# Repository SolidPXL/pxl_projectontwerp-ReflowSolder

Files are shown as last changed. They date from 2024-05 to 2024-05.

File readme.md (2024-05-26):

Final exam project for the PXL course 'Project Ontwerp' (Translated 'Project design')

The goal was to design a product from start to finish and make a first prototype version and to present our project in front of our professors. We got scored on our PCB design, Case design, project pitch, documentation and our development during the project.

The project is inspired by the AfterEarth [Solder Reflow plate](https://github.com/AfterEarthLTD/Solder-Reflow-Plate/tree/main)

V1 is what was submitted for points. Plans are to fix the issues that have been found and release a V2

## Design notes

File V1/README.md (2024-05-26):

# Reflow Solder Plate Version 1

# WARNING:
### It is not recommended to make this project as there are tons of issues, see the 'Known issues' below

## Features
- 10x10cm hot plate
- EST 100W PCB hot plate
- Soldering with reflow curves
- LCD display with rotary encoder controls
- 3D printed casing
- Case temperature management with fan and temp sensor
- Fused power socket
- Multiple boards, compact assembly

## Guide
### Electronics
Download the provider gerber files and upload to your favorite PCB manufacturer. It is recommended to purchase a stencil too.
Settings for both PCBs:

| Setting | Value |
| --- | --- |
| Base Material | FR-4 |
| Layers: | 2 |
| Dimension: | 100 mm* 100 mm |
| PCB Qty: | 5 |
| Product Type | Industrial/Consumer electronics |
| Different Design | 1 |
| Delivery Format | Single PCB |
| PCB Thickness: | 1.6 |
| Impedance Control | no |
| PCB Color | Green |
| Silkscreen | White |
| Material Type | FR4-Standard TG 135-140 |
| Via Covering | Tented |
| Surface Finish | HASL(with lead) |
| Deburring/Edge rounding | No |
| Outer Copper Weight | 1 oz |
| Gold Fingers | No |
| Flying Probe Test | Fully Test |
| Castellated Holes | no |
| Edge Plating | No	|
| 4-Wire Kelvin Test | No |
| Paper between PCBs | No |
| Appearance Quality | IPC Class 2 Standard	Confirm |
| Silkscreen Technology | Ink-jet/Screen Printing Silkscreen |
| Board Outline Tolerance |±0.2mm(Regular) |

Other manufacturing settings might work too, these are which I used when ordering at JLCPCB

After ordering the PCBs and the parts, which can be found in the BOM, you can start soldering. You can use the BOM to know where each component goes.

### Case
You can now print the casing, files can be found in the repo. For the assebly you will need 6 M2(2 long, 4 short), 8 M3 and 2 M4 screws and inserts.

### Assembly
There is a seperate file in the repo that goes in depth on how to assemble the case

## Known issues
Due to the scope and time limitation of the project there are numerous known issues
- Headers used for power delivery for the heating circuitry is not capable of handling the currents
- Pads on the RFR board are too small to solder the wires from the transformer to.
- Annular rings on the mounting holes are too small
- Resistance calculation on the hot plate is wrong, too low resistance -> pulls too much current
- Tolerances on some case parts are too narrow (especially when 3D printing)
- Hole for the LCD display is too small
- Standoffs bend and fold when inserting the threaded inserts
- No support for a second case fan
- No code available due to time limitation

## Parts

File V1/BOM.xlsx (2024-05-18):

ID | Type | Package | Designator | Value | MAN. NUM. | MANUFACTURER | Price/1 | Price/10 | Min. Qty | Id. Qty | Link
1 | MLCC | 0603 | C1,C2,C3,C4,C5,C6,C7 | 100nF | C0603C104J5RACTU | Kemet | 0.093 | 0.043 | 10 | 100 | https://www.mouser.be/ProductDetail/KEMET/C0603C104J5RACTU?qs=kWB%252BwhWP5%2FerIl8pCaFi1A%3D%3D
2 | AEC | Radial | C8 | 1000uF | 860020475018 | Wurth | 0.53 | 0.517 | 1 | 1 | https://www.mouser.be/ProductDetail/Wurth-Elektronik/860020475018
3 | AEC | Radial | C9 | 100uF | ESH107M025AE3KA | Kemet | 0.042 | 0.039 | 1 | 1 | https://www.mouser.be/ProductDetail/KEMET/ESK107M025AC3AA?qs=Z46kSA%2FmtFiEo%2F6fDW5ebA%3D%3D
4 | MLCC | Radial | C10,C11 | 1uF | C333C105M5U5TA7301 | Kemet | 0.4 | 0.241 | 1 | 10 | https://www.mouser.be/ProductDetail/KEMET/C333C105M5U5TA7301
5 | TF | 0603 | R1,R2,R3,R7 | 1K | RCC06031K00FKEA | Vishay | 0.121 | 0.041 | 10 | 100 | https://www.mouser.be/ProductDetail/Vishay-Dale/RCC06031K00FKEA
6 | TF | 0603 | R4 | 10K | CRCW060310K0FKEAC | Vishay Dale | 0.093 | 0.029 | 1 | 100 | https://www.mouser.be/ProductDetail/Vishay-Dale/CRCW060310K0FKEAC
7 | TF | 0603 | R5 | 4,7K | AC0603JR-074K7L | Yaguo | 0.093 | 0.012 | 1 | 100 | https://eu.mouser.com/ProductDetail/YAGEO/AC0603JR-074K7L?qs=ygRr%2FtkhtetTh0gFFMX2qg%3D%3D
8 | TF | 0603 | R6 | 100K | RE0603FRE07100KL | Yageo | 0.093 | 0.015 | 1 | 100 | https://www.mouser.be/ProductDetail/YAGEO/RE0603FRE07100KL
9 | Connector | 1x2pinMS | J1,J2,J3,J4,J7,J8,J9,J10 |  | 292132-2 | TE connectivity | 0.446 | 0.392 | 10 | 10 | https://www.mouser.be/ProductDetail/TE-Connectivity/292132-2?qs=uJX40y%252BSWqjXcf3H59FIEQ%3D%3D
10 | Connector | 1x3pinM | J5 |  | 2PH1-03-UA | Adam Tech | 0.121 | 0.082 | 0 | 10 | https://www.mouser.be/ProductDetail/Adam-Tech/2PH1-03-UA?qs=HoCaDK9Nz5dpKQTwHap8WA%3D%3D
11 | Connector | 1x4pinMS | J6 |  | 292132-4 | TE connectivity | 0.381 | 0.319 | 1 | 1 | https://www.mouser.be/ProductDetail/TE-Connectivity/292132-4?qs=pO4cRNoTGSbE0hNJ6cJ%2Fkg%3D%3D
12 | MCU | TQFP | IC1 |  | ATMEGA4809-AFR | Microchip Technology | 1.79 | 1.79 | 1 | 1 | https://eu.mouser.com/ProductDetail/Microchip-Technology/ATMEGA4809-AFR?qs=lYGu3FyN48fyX8GjkvcD6Q%3D%3D
13 | NTC thermistor | Wire lead | THERMISTOR |  | NKA272C1B1 | Amphennol advanced sensors | 1.51 | 1.13 | 1 | 1 | https://www.mouser.be/ProductDetail/Amphenol-Advanced-Sensors/NKA272C1B1
14 | Regulator | THT | REG1 | 5V | L78L05ACZ-AP | STMicroelectronics | 0.465 | 0.344 | 1 | 1 of 10 | https://www.mouser.be/ProductDetail/STMicroelectronics/L78L05ACZ-AP?qs=b1HjDA41YmFrA6GoH2rz8Q%3D%3D
15 | Zener | THT | D1 | 16V | BZX85B16-TAP | Vishay | 0.214 | 0.149 | 1 | 1 | https://www.mouser.be/ProductDetail/Vishay-Semiconductors/BZX85B16-TAP?qs=yIvl1B2wDi77%252Bpyj7jHV%252Bg%3D%3D
16 | Rectifier | SMC-4 | D2, D3, D4, D5 |  | S8KS-E3/I | Vishay | 0.521 | 0.443 | 10 | 10 | https://www.mouser.be/ProductDetail/Vishay-General-Semiconductor/S8KS-E3-I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
17 | Receptor | Fused | Receptor |  | 06A2 | Delta electronics | 6.9 | 6.41 | 1 | 1 | https://www.mouser.be/ProductDetail/Delta-Electronics/06A2?qs=%2FW4LtXOBxKsfz6XFF6eGRQ%3D%3D
18 | Transformer | Board mount | TR1 |  | FD8-16 | Triad Magnetics | 26.402 | 24.4 | 1 | 1 | https://www.digikey.be/en/products/detail/triad-magnetics/FD8-16/4878696
19 | MOSFET | THT | Q1 |  | IRFB7545PBF | Infineon technologies | 0.586 | 0.508 | 1 | 1 | https://www.mouser.be/ProductDetail/Infineon-Technologies/IRFB7545PBF?qs=a7rcPCEf1Q%252BjvB7f7k7q9g%3D%3D
22
Optional
20 |  | 1x2pinM |  |  | 1-1123723-2 | TE connectivity | 0.177 | 0.131 | 10 | 10 | https://eu.mouser.com/ProductDetail/TE-Connectivity-AMP/1-1123723-2?qs=3y%252B3RyvVzbfjiwlVBkpjbA%3D%3D
21 |  | wirecrimp |  |  | 1-1123722-2 | TE connectivity | 0.149 | 0.096 | 10 | 10 | https://eu.mouser.com/ProductDetail/TE-Connectivity-AMP/1-1123722-2?qs=3y%252B3RyvVzbeziCj0iYmNwg%3D%3D
22 |  | SMD |  |  | MMFTN6001 | Diotec Semiconductor | 0.112 | 0.082 | 1 | 10 | https://www.mouser.be/ProductDetail/Diotec-Semiconductor/MMFTN6001?qs=Wj%2FVkw3K%252BMBEABncUaRa2w%3D%3D
10K weerstand vervangen door een 1K? Dit is toch enkel als pulldown
Alle 1,2P, muv degene voor de temp sensor vervangen door een shielded met connector systeem?
Een ander soort temperatuur sensor die zeker temperatuur aankan tot 250 graden
4pin
https://www.mouser.be/ProductDetail/TE-Connectivity/292132-4?qs=pO4cRNoTGSbE0hNJ6cJ%2Fkg%3D%3D | Male shrouded
https://www.mouser.be/ProductDetail/TE-Connectivity/173977-4?qs=4hg9R9g9MDt3QfUOn7UUVQ%3D%3D
2pin
https://www.mouser.be/ProductDetail/TE-Connectivity/292132-2?qs=uJX40y%252BSWqjXcf3H59FIEQ%3D%3D | Male shrouded
https://www.mouser.be/ProductDetail/TE-Connectivity/173977-2?qs=uJX40y%252BSWqjnZauWtWGv2w%3D%3D
zener msd
https://eu.mouser.com/ProductDetail/Vishay-Semiconductors/BZD27C16P-E3-08?qs=dxY6ZrAOask1ZgTH5Xp%252BJg%3D%3D

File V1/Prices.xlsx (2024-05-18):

Item | Unit price | Used amount | Purchased amount | Fair total | Actual total | Vendor | Shop | Delivery costs
237-1767-ND | €21.820 | 1 | 1 | €21.820 | €21.820 | DK | Mouser | €20.00
C0603C104J5RACTU | €0.020 | 7 | 100 | €0.140 | €2.000 | M | JLCPCB | €20.77
860020475018 | €0.517 | 1 | 10 | €0.517 | €5.170 | M | Digikey | €0.00
ESK107M025AC3AA | €0.106 | 1 | 10 | €0.106 | €1.060 | M |  | €40.77
C333C105M5U5TA7301 | €0.402 | 2 | 10 | €0.804 | €4.020 | M
RCC06031K00FKEA | €0.023 | 4 | 100 | €0.092 | €2.300 | M
CRCW060310K0FKEAC | €0.011 | 1 | 100 | €0.011 | €1.100 | M
AC0603JR-074K7L | €0.007 | 1 | 100 | €0.007 | €0.700 | M
RE0603FRE07100KL | €0.008 | 1 | 100 | €0.008 | €0.800 | M
292132-2 | €0.392 | 8 | 10 | €3.136 | €3.920 | M
2PH1-03-UA | €0.100 | 1 | 5 | €0.100 | €0.500 | M
292132-4 | €0.381 | 1 | 1 | €0.381 | €0.381 | M
ATMEGA4809-AFR | €1.790 | 1 | 1 | €1.790 | €1.790 | M
NKA272C1B1 | €1.510 | 1 | 1 | €1.510 | €1.510 | M
L78L05ACZ-AP | €0.344 | 1 | 10 | €0.344 | €3.440 | M
BZD27C16P-E3-08 | €0.244 | 1 | 10 | €0.244 | €2.440 | M
S8KS-E3/I | €0.443 | 4 | 10 | €1.772 | €4.430 | M
06A2 | €6.900 | 1 | 1 | €6.900 | €6.900 | M
IRFB7545PBF | €0.508 | 1 | 10 | €0.508 | €5.080 | M
173977-2 | €0.114 | 8 | 10 | €0.912 | €1.140 | M
173977-4 | €0.493 | 1 | 1 | €0.493 | €0.493 | M
Filament | €22.500 | 1 | 1 | €22.500 | €22.500 | 123
Fan | €1.580 | 1 | 1 | €1.580 | €1.580 | Ali
Oled | €2.520 | 1 | 1 | €2.520 | €2.520 | Ali
Logic Stencil | €1.288 | 1 | 5 | €1.288 | €6.440 | JLC
PCB logic | €0.368 | 1 | 5 | €0.368 | €1.840 | JLC
PCB heater | €0.736 | 1 | 5 | 0.736 | 3.68 | JLC
 |  |  | Subt. | €70.59 | €109.55
 |  |  | Delivery | €26.27 | €40.77
 |  |  | Total | €96.86 | €150.32

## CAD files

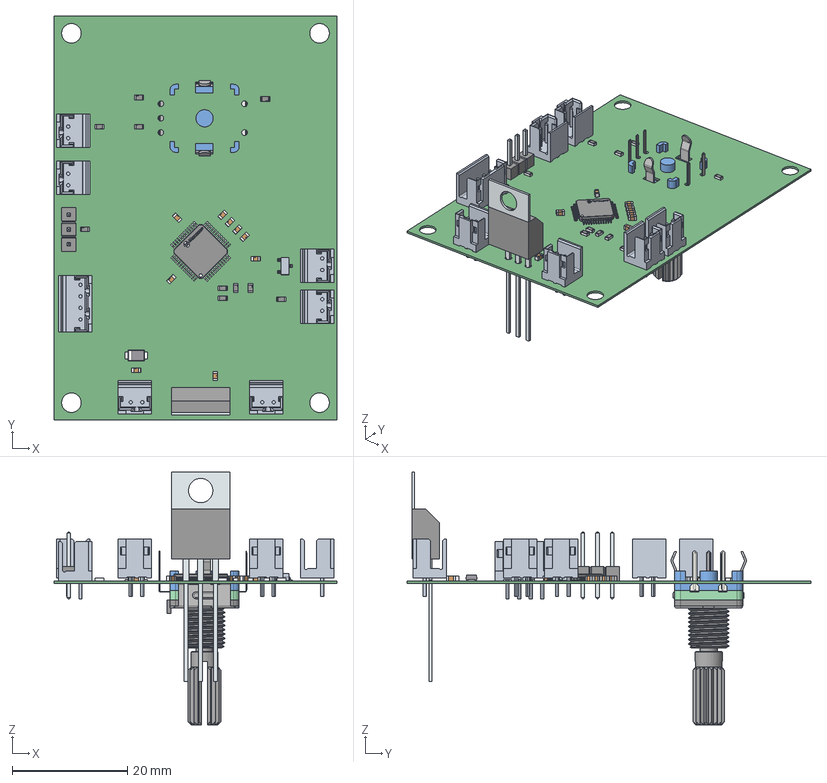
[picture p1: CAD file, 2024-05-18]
V1/Altium/ReflowIron-01-Logic/ControlBoard.step
49.0 x 70.0 x 43.8 mm
terminal x 10
top x 10
logo x 11
p200_SOT-23
Pins x 9
Walsin Technology Logo x 9
LeadsArray
Tab
PinsArray
pins
EC11_Rotary_Encoder_Switched
DO-219AB

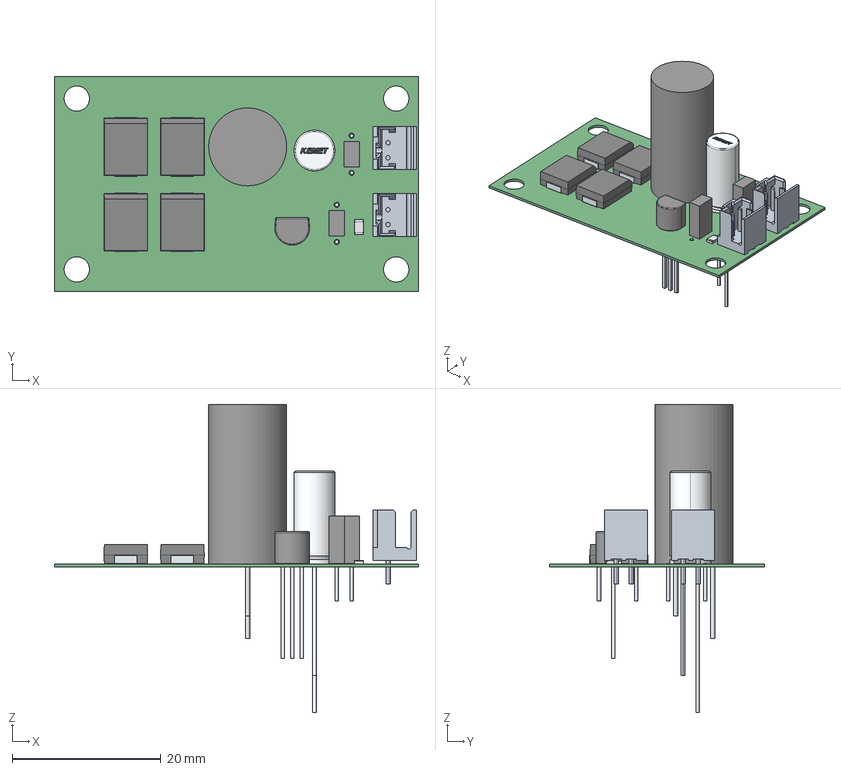
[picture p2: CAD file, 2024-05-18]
V1/Altium/ReflowIron-02-PSU/PSU.step
49.0 x 29.0 x 41.5 mm
TS110-7A1-AP_Bulk Pack (Straight)
STMicro Logo
FilletPin1 x 4
FilletPin2 x 4
Leads x 2
SimpleBody
Pin1
Pin2

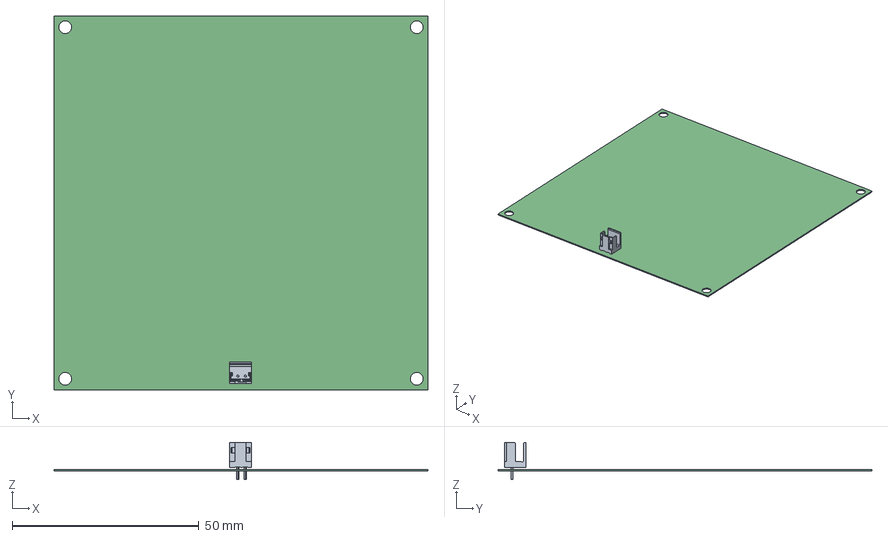
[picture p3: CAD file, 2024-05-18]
V1/Altium/ReflowIron-03-Heatbed/Heatbed.step
100.0 x 100.0 x 10.0 mm

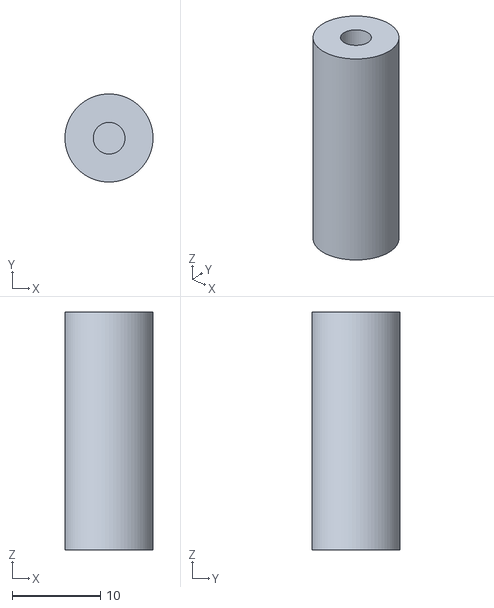
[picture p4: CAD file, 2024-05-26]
V1/Casing/Pillar.stl
10.0 x 10.0 x 27.0

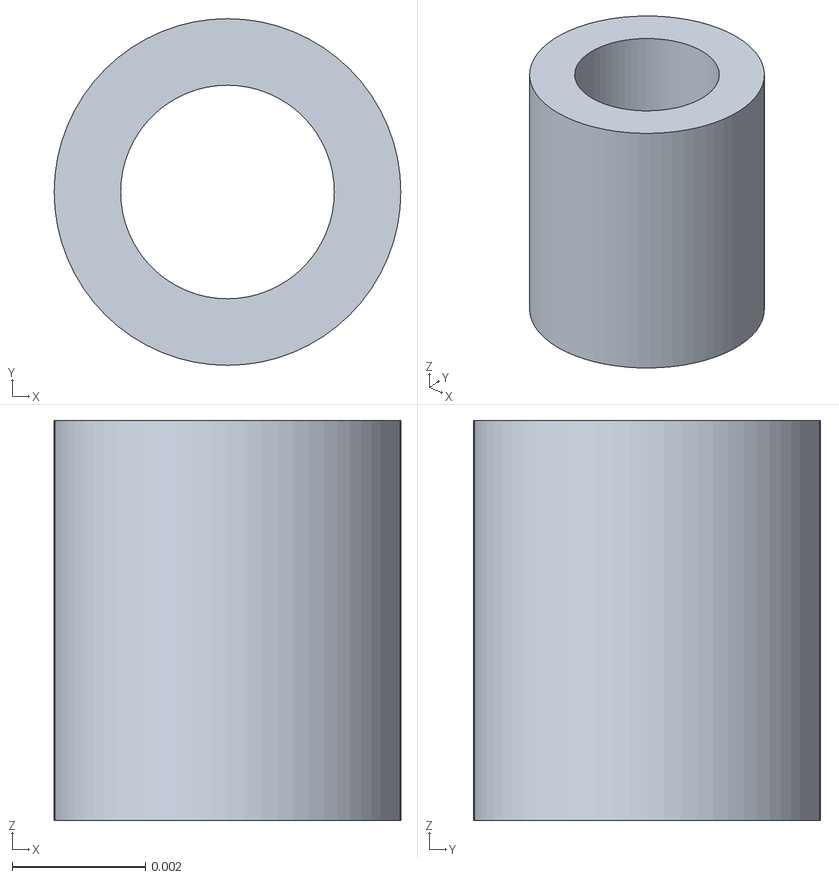
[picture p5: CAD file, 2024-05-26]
V1/Casing/Spacer.stl
0.0052 x 0.0052 x 0.006

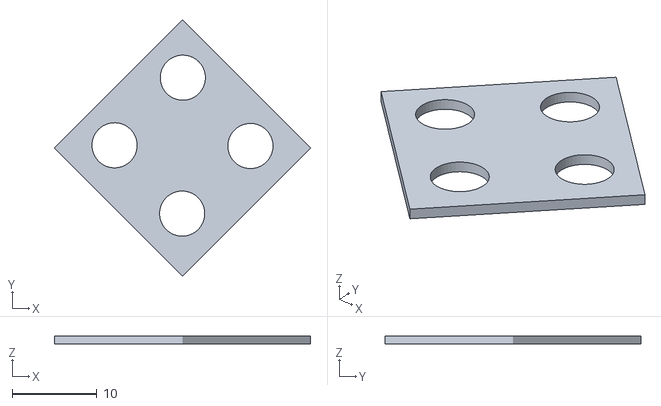
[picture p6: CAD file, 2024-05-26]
V1/Casing/Body4.stl
30.1 x 30.1 x 1.00

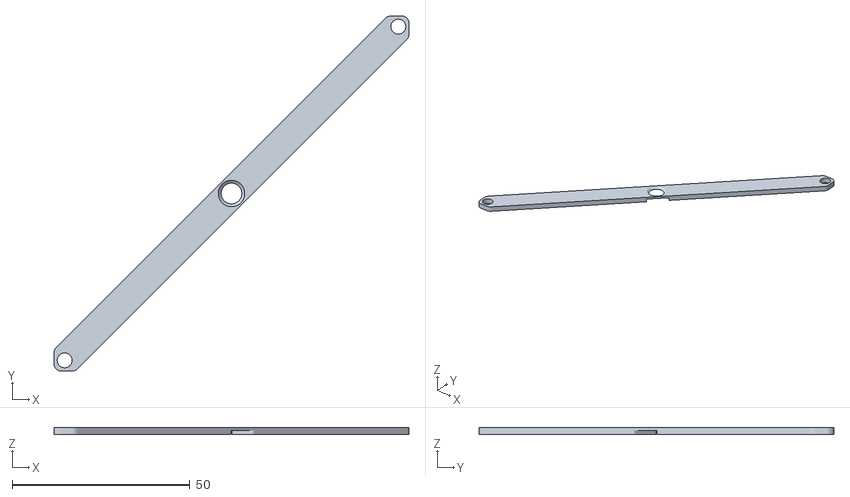
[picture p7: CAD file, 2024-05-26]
V1/Casing/Top arm.stl
100.0 x 100.0 x 2.00

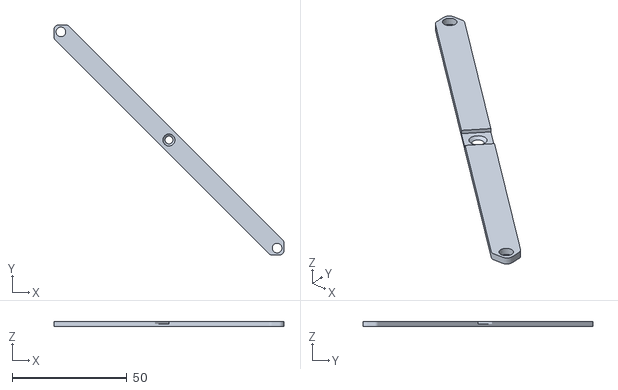
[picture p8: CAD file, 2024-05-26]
V1/Casing/Bottom arm.stl
100.0 x 100.0 x 2.00

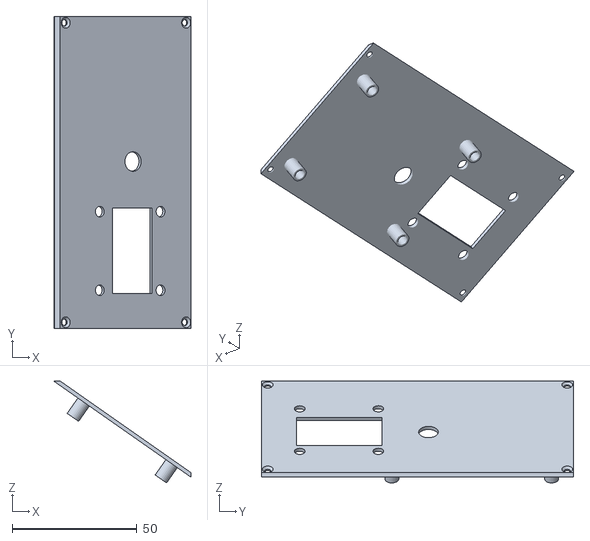
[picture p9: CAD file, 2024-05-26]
V1/Casing/Body1.stl
54.8 x 125.0 x 40.8

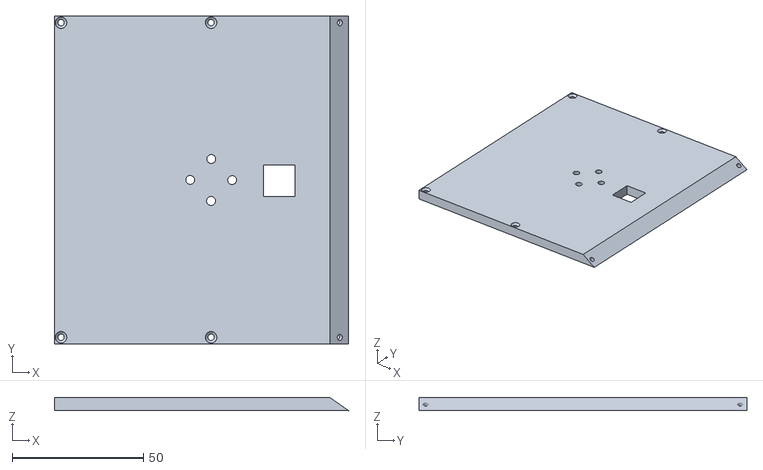
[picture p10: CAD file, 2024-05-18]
V1/Casing/Lid.stl
112.1 x 125.0 x 5.00

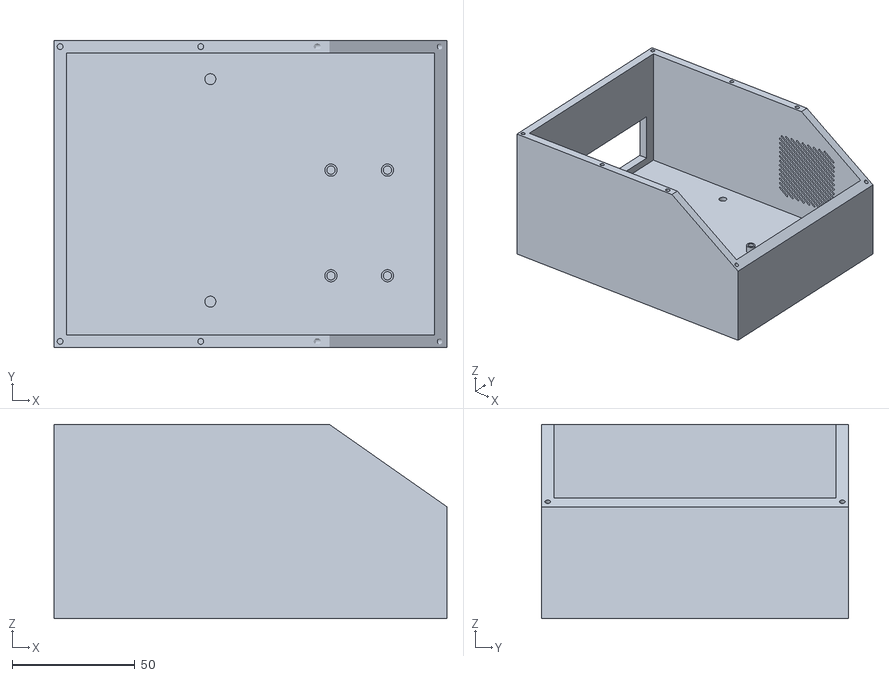
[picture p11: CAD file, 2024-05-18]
V1/Casing/Body.stl
160.0 x 125.0 x 79.0

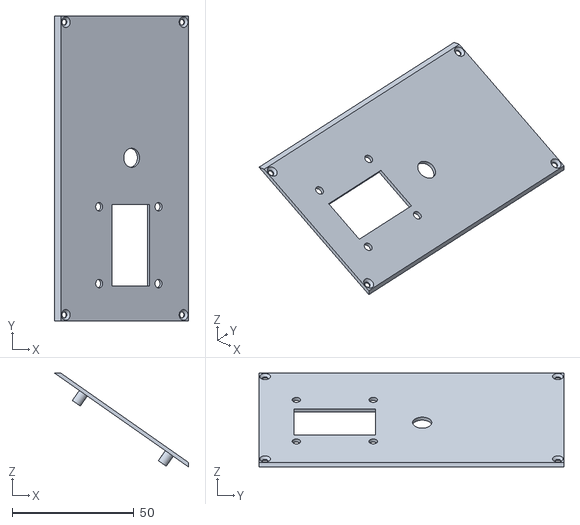
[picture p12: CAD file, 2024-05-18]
V1/Casing/frontplate.stl
55.0 x 125.0 x 38.5

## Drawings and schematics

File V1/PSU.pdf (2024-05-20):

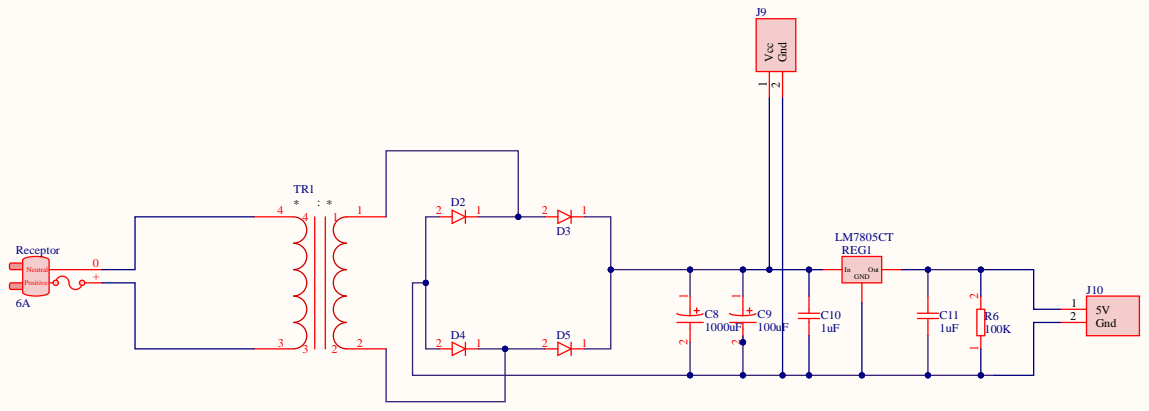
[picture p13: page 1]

Title Power supply unit | Part of Reflow solder iron

Component PSU | Revision 1.0.0 | Organisation PXL

Creation date 11/03/2024 | Sheet 1 Of 1
Last updated 12/03/2023 | Author Axel Colson

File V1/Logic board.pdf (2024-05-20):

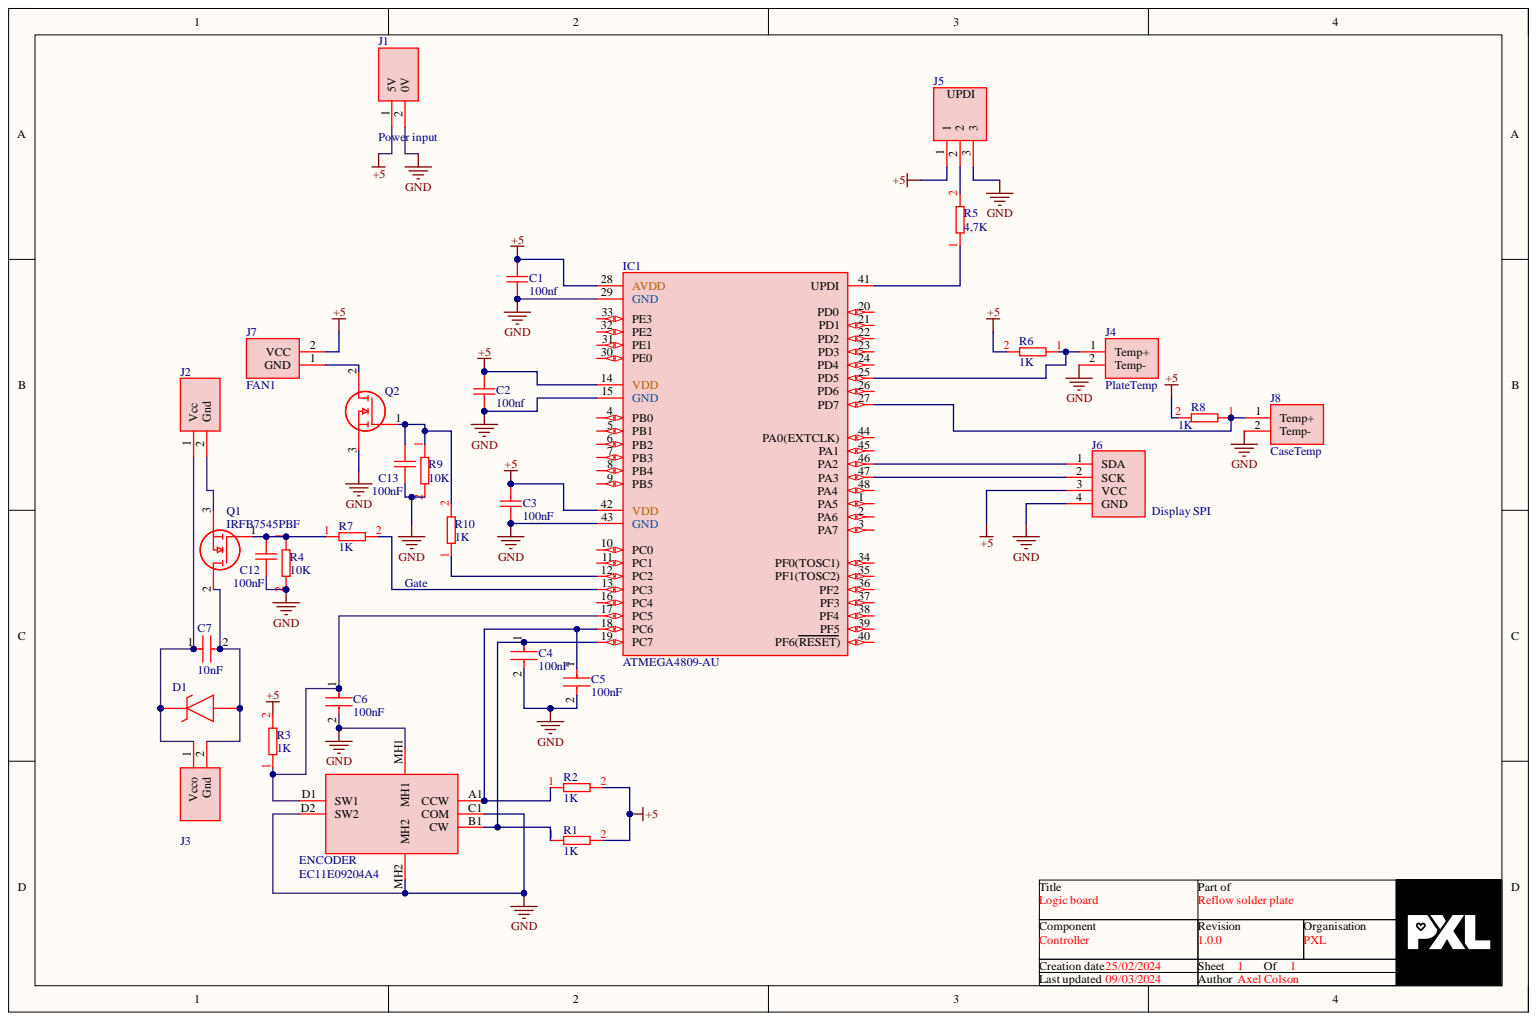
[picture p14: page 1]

1 8
1 9

T i tl e L o g ic b oard | Part o f Refl o w s o l der p lat e

Comp o n en t Co n tro l l er | Rev i s i o n 1.0 . 0 | Organ i s ati o n PX L

Creat i o n dat e 2 5 / 0 2 / 2 0 2 4 | Shee t 1 O f 1
Las t u p dated 0 9 / 0 3 / 2 0 2 4 | A u t h o r A xel Co l s o n

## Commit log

2024-05-26 STL changes
    [Body1.stl, Body4.stl, Bottom arm.stl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]
2024-05-26 Added gerber files
